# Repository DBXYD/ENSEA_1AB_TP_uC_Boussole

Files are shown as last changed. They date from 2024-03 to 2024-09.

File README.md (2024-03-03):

# ENSEA_1AB_TP_uC_Boussole

## TP

### PCB
Composants : 
* [NUCLEO-L476RG](https://www.st.com/en/evaluation-tools/nucleo-l476rg.html)
* [Magnétomètre 3 axes MMC5603 ADA5579](https://www.gotronic.fr/art-magnetometre-3-axes-mmc5603-ada5579-35829.htm)
* [GPS Tel0094](https://www.gotronic.fr/art-module-gps-tel0094-25732.htm)
* [Microcontroleur pour simulation trame NMEA STM32C011J4M6](https://fr.farnell.com/stmicroelectronics/stm32c011j4m6/mcu-arm-32-bits-48mhz-nsoic-8/dp/4138300)
* [Moteur pas à pas 17hs15-0404s](https://www.gotronic.fr/art-moteur-17hs15-0404s-18354.htm)
* [Driver de moteur pas à pas TMC2225](https://fr.farnell.com/trinamic/tmc2225-sa-t/driver-de-moteur-2a-40-a-125-c/dp/3690353?st=TMC2225-SA-T)
* [Codeur rotatif](https://fr.farnell.com/bourns/pec12r-2220f-s0024/encoder-quadrature-24ppr-15rpm/dp/4014827)
* [Ecran OLED 0.96"](https://www.gotronic.fr/art-afficheur-oled-0-96-i2c-oled01-31506.htm)
* [Mesure de courant NCS199A3RSQT2G](https://fr.farnell.com/on-semiconductor/ncs199a3rsqt2g/ampli-musure-de-cour-40khz-40/dp/2981170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)

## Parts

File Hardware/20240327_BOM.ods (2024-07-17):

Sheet: Farnell
Value | Footprint | MPN | Quantity | Dispo | Farnell | Total
Conn_01x09 | Connector_JST:JST_XH_S9B-XH-A_1x09_P2.50mm_Horizontal | S9B-XH-A (LF)(SN) | 100 | 9249 | 0,21 € | 21,00 €
Conn_01x09 |  | XHP-9 | 100 | 2988 | 0,12 € | 12,00 €
TMC2225-SA-T | Package_SO:HTSSOP-28-1EP_4.4x9.7mm_P0.65mm_EP2.85x5.4mm_ThermalVias | TMC2225-SA-T | 100 | 1035 | 1,58 € | 158,00 €
STM32C011J4Mx | Package_SO:SOIC-8_3.9x4.9mm_P1.27mm | STM32C011J4M6 | 100 | 142 | 0,75 € | 75,00 €
AMS1117-3.3 | Package_TO_SOT_SMD:SOT-223-3_TabPin2 | AZ1117CH2-3.3TRG1 | 100 | 467 | 0,14 € | 14,00 €
 | Connector 2x19 | SSW-119-01-T-D | 250 | 1478 | 3,12 | 780,00 €
NCS199A3RSQT2G | Package_TO_SOT_SMD:SOT-363_SC-70-6 | NCS199A3RSQT2G | 100 | 375 | 0,45 € | 45,00 €
SW_Push_DPDT | Button_Switch_SMD:SW_DPDT_CK_JS202011JCQN | JS202011JCQN | 100 | 3904 | 0,51 € | 51,00 €
Conn_03x06 |  | SAMTEC TSW-106-05-F-T | 100 | 0 |  | 0,00 €
110m | Resistor_SMD:R_0603_1608Metric_Pad0.98x0.95mm_HandSolder | MFL0603R1100FB | 100 | 4970 | 0,08 € | 8,00 €
680m | Resistor_SMD:R_1206_3216Metric_Pad1.30x1.75mm_HandSolder | WW12PR680FTL | 200 | 2340 | 0,13 € | 26,00 €
400m | Resistor_SMD:R_0402_1005Metric | WW04PR400FTL | 200 | 5660 | 0,104 | 20,80 €
 | Alimentation 230VAC/12VDC | PELL0219 | 100 | 177 | 4,80 € | 480,00 €
 |  |  |  |  |  | 1 690,80 €

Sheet: WE
Value | Footprint | MPN | Quantity | Dispo | WE | Total | MPN | Quantity
10n | Capacitor_SMD:C_0402_1005Metric | WE 885012205050 | 900 |  | 0,01 € | 6,30 € | WE 885012205050 | 1000
22n | Capacitor_SMD:C_0402_1005Metric | WE 885012205052 | 100 |  | 0,01 € | 1,20 € | WE 885012205052 | 500
100n | Capacitor_SMD:C_0402_1005Metric | WE 885012105018 | 700 |  | 0,02 € | 14,70 € | WE 885012105018 | 1000
1u | Capacitor_SMD:C_0402_1005Metric | WE 885012105012 | 300 |  | 0,20 € | 60,90 € | WE 885012105012 | 500
10u | Capacitor_SMD:C_0402_1005Metric | WE 885012105020 | 200 |  | 0,28 € | 55,00 € | WE 885012105020 | 500
10u | Capacitor_SMD:CP_Elec_4x5.7 | WE 865060440001 | 200 |  | 0,16 € | 31,80 € | WE 865060440001 | 200
4u7 | Capacitor_SMD:C_0402_1005Metric | WE 885012105008 | 200 |  | 0,22 € | 44,80 € | WE 885012105008 | 200
 | Step-down 5V | WE 173010542 | 100 |  | 8,94 € | 894,00 € | WE 173010542 | 100
AMBER_LED | LED_SMD:LED_0603_1608Metric | WE 150060AS55040 | 100 |  | 0,12 € | 11,60 € | WE 150060AS55040 | 500
GREEN_LED | LED_SMD:LED_0603_1608Metric | WE 150060GS55040 | 500 |  | 0,18 € | 91,00 € | WE 150060GS55040 | 500
RED_LED | LED_SMD:LED_0603_1608Metric | WE 150060RS55040 | 600 |  | 0,15 € | 87,60 € | WE 150060RS55040 | 1000
YELLOW_LED | LED_SMD:LED_0603_1608Metric | WE 150060YS55040 | 100 |  | 0,15 € | 14,60 € | WE 150060YS55040 | 500
Conn_02x02_Counter_Clockwise | Connector_PinHeader_2.54mm:PinHeader_2x02_P2.54mm_Vertical_SMD | WE 61000421121 | 100 |  | 0,49 € | 49,00 € | WE 61000421121 | 200
Conn_02x10_Odd_Even | Connector_PinHeader_2.54mm:PinHeader_2x10_P2.54mm_Vertical_SMD | WE 61002021121 | 100 |  | 1,85 € | 185,00 € | WE 61000621121 | 100
RotaryEncoder_Switch | libs:482016514001_Mechanical_Incremental_Encoder_Switch | WE 482016514001 | 100 |  | 2,96 € | 296,00 € | WE 61000821121 | 100
SW_Push | Button_Switch_SMD:SW_Push_1P1T_NO_6x6mm_H9.5mm | WE 430182070816 | 700 |  | 0,41 € | 289,10 € | WE 61001021121 | 100
SW_SPDT | libs:472121020311 | WE 472121020311 | 100 |  | 5,32 € | 532,00 € | WE 61001221121 | 100
 | libs:SC70-5L | WE 82402374 | 600 |  | 0,58 € | 346,80 € | WE 61001421121 | 100
 | libs:SC70-6L | WE 82402375 | 200 |  | 0,59 € | 117,40 € | WE 61001621121 | 100
 |  |  |  |  |  | 3 128,80 € | WE 61002021121 | 200
 |  |  |  |  |  |  | WE 482016514001 | 150
 |  |  |  |  |  |  | WE 430182070816 | 1000
 |  |  |  |  |  |  | WE 472121020311 | 200
 |  |  |  |  |  |  | WE 82402374 | 1000
 |  |  |  |  |  |  | WE 82402375 | 500

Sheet: Gotronic
Value | Code Gotronic | MPN | Quantity | Dispo | Tarif | Total
Stepper | 31115 | 14HM11-0404S | 100 | 24 | 18,58 | 1 858,00 €
Magnétomètre | 37683 | BMM150 SEN0419 | 100 | 22 | 6,92 | 692,00 €
GPS | 35014 | TEL0094 | 100 | 15 | 15,5 | 1 550,00 €
OLED | 36688 | SBC-01 | 100 | 168 | 6,25 | 625,00 €
 |  |  |  |  |  | 4 725,00 €

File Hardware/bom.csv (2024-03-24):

Value | Footprint | MPN | Quantity | Dispo | Farnell | Total
Conn_01x09 | Connector_JST:JST_XH_S9B-XH-A_1x09_P2.50mm_Horizontal | S9B-XH-A (LF)(SN) | 100 | 9249 | 0,21 € | 20,90 €
Conn_01x09 |  | XHP-9 | 100 | 2988 | 0,12 € | 12,10 €
TMC2225-SA-T | Package_SO:HTSSOP-28-1EP_4.4x9.7mm_P0.65mm_EP2.85x5.4mm_ThermalVias | TMC2225-SA-T | 100 | 1035 | 1,58 € | 158,00 €
STM32C011J4Mx | Package_SO:SOIC-8_3.9x4.9mm_P1.27mm | STM32C011J4M6 | 100 | 142 | 0,75 € | 75,40 €
AMS1117-3.3 | Package_TO_SOT_SMD:SOT-223-3_TabPin2 | AZ1117CH2-3.3TRG1 | 100 | 467 | 0,14 € | 13,70 €
 | Connector 2x19 | TSW-119-19-T-D | 250 | 1478 | 1,51 € | 377,50 €
NCS199A3RSQT2G | Package_TO_SOT_SMD:SOT-363_SC-70-6 | NCS199A3RSQT2G | 100 | 375 | 0,45 € | 44,70 €
SW_Push_DPDT | Button_Switch_SMD:SW_DPDT_CK_JS202011JCQN | JS202011JCQN | 100 | 3904 | 0,51 € | 51,30 €
Conn_03x06 |  | SAMTEC TSW-106-05-F-T | 100 | 0 |  | 0,00 €
110m | Resistor_SMD:R_0603_1608Metric_Pad0.98x0.95mm_HandSolder | MFL0603R1100FB | 100 | 4970 | 0,08 € | 8,20 €
680m | Resistor_SMD:R_1206_3216Metric_Pad1.30x1.75mm_HandSolder | WW12PR680FTL | 200 | 2340 | 0,13 € | 25,20 €
30m | Resistor_SMD:R_0402_1005Metric | ERJ2RKF30R1X | 100 | 31860 | 0,01 € | 0,50 €
 | Alimentation 230VAC/12VDC | PELL0219 | 100 | 177 | 4,80 € | 480,00 €
 |  |  |  |  |  | 1 267,50 €

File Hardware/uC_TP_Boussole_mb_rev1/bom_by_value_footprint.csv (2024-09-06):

Reference | Value | Datasheet | Footprint | Qty | DNP
C201,C203 | 10u | ~ | Capacitor_SMD:CP_Elec_4x5.7 | 2
C202,C205,C302,C304,C404,C601,C904 | 100n | ~ | Capacitor_SMD:C_0402_1005Metric | 7
C204 | 22n | ~ | Capacitor_SMD:C_0402_1005Metric | 1
C206,C301 | 4u7 | ~ | Capacitor_SMD:C_0402_1005Metric | 2
C303,C501,C502,C503,C504,C505,C901,C902,C903 | 10n | ~ | Capacitor_SMD:C_0402_1005Metric | 9
C305,C701,C801 | 1u | ~ | Capacitor_SMD:C_0402_1005Metric | 3
C401,C403 | 10u | ~ | Capacitor_SMD:C_0402_1005Metric | 2
C402 | 22u | ~ | Capacitor_SMD:CP_Elec_5x5.4 | 1
D201,D301,D401,D402,D403,D502 | RED_LED | https://www.we-online.com/components/products/datasheet/150060RS55040.pdf | LED_SMD:LED_0603_1608Metric | 6
D302,D511 | WE 82402375 | https://www.we-online.com/components/products/datasheet/82402375.pdf | libs:SC70-6L | 2
D501,D510,D701,D702,D801,D901 | WE 82402374 | https://www.we-online.com/components/products/datasheet/82402374.pdf | libs:SC70-5L | 6
D503 | AMBER_LED | https://www.we-online.com/components/products/datasheet/150060AS55040.pdf | LED_SMD:LED_0603_1608Metric | 1
D504 | YELLOW_LED | https://www.we-online.com/components/products/datasheet/150060YS55040.pdf | LED_SMD:LED_0603_1608Metric | 1
D505,D506,D507,D508,D509 | GREEN_LED | https://www.we-online.com/components/products/datasheet/150060GS55040.pdf | LED_SMD:LED_0603_1608Metric | 5
H101,H102,H103,H104,H105,H106,H107,H108 | MountingHole_Pad | ~ | MountingHole:MountingHole_3.2mm_M3_Pad | 8
J201 | Conn_01x04 | ~ | Connector_JST:JST_XH_B4B-XH-A_1x04_P2.50mm_Vertical | 1
J302 | Conn_01x04 | ~ | libs:Grove_PHS-4AW | 1
J303 | Conn_01x06 | ~ | Connector_PinHeader_2.54mm:PinHeader_1x06_P2.54mm_Vertical_SMD_Pin1Left | 1
J402 | Conn_02x02_Counter_Clockwise | https://www.we-online.com/components/products/datasheet/61000421121.pdf | Connector_PinHeader_2.54mm:PinHeader_2x02_P2.54mm_Vertical_SMD | 1
J403 | Barrel_Jack_Switch | ~ | libs:694106105102 | 1
J501,J502,J503 | Conn_01x06 | ~ | Connector_PinHeader_2.54mm:PinHeader_1x06_P2.54mm_Vertical | 3
J504 | Conn_02x10_Odd_Even | https://www.we-online.com/components/products/datasheet/61002021121.pdf | Connector_PinHeader_2.54mm:PinHeader_2x10_P2.54mm_Vertical_SMD | 1
J701 | Conn_01x09 | ~ | Connector_JST:JST_XH_S9B-XH-A_1x09_P2.50mm_Horizontal | 1
J801 | Conn_01x04 | ~ | libs:SBC-OLED01 | 1
R201 | 110m | ~ | Resistor_SMD:R_0603_1608Metric_Pad0.98x0.95mm_HandSolder | 1
R202,R203 | 680m | ~ | Resistor_SMD:R_1206_3216Metric_Pad1.30x1.75mm_HandSolder | 2
R204,R404 | 820 | ~ | Resistor_SMD:R_0402_1005Metric | 2
R301,R302,R509,R510,R511,R512,R513,R514,R515,R516,R517,R518,R901,R902,R903,R904,R905,R906 | 10k | ~ | Resistor_SMD:R_0402_1005Metric | 18
R303,R501,R503 | 800 | ~ | Resistor_SMD:R_0402_1005Metric | 3
R401 | 1k | ~ | Resistor_SMD:R_0805_2012Metric | 1
R402 | 5k1 | ~ | Resistor_SMD:R_0402_1005Metric | 1
R403 | 1k6 | ~ | Resistor_SMD:R_0402_1005Metric | 1
R502 | 850 | ~ | Resistor_SMD:R_0402_1005Metric | 1
R504,R505,R506,R507,R508 | 400 | ~ | Resistor_SMD:R_0402_1005Metric | 5
R601 | 400m | ~ | Resistor_SMD:R_0402_1005Metric | 1
R801,R802 | 1k | ~ | Resistor_SMD:R_0402_1005Metric | 2
SW301,SW302,SW501,SW502,SW503,SW504,SW505 | SW_Push | ~ | Button_Switch_SMD:SW_Push_1P1T_NO_6x6mm_H9.5mm | 7
SW303 | SW_Push_DPDT | ~ | Button_Switch_SMD:SW_DPDT_CK_JS202011JCQN | 1
SW401 | SW_SPDT | https://www.we-online.com/components/products/datasheet/472121020311.pdf | libs:472121020311 | 1
SW901 | RotaryEncoder_Switch | https://www.we-online.com/components/products/datasheet/482016514001.pdf | libs:482016514001_Mechanical_Incremental_Encoder_Switch | 1
U201 | TMC2225-SA-T | https://www.analog.com/media/en/technical-documentation/data-sheets/TMC2225_datasheet_rev1.15.pdf | Package_SO:HTSSOP-28-1EP_4.4x9.7mm_P0.65mm_EP2.85x5.4mm_ThermalVias | 1
U301 | STM32C011J4Mx | https://www.st.com/resource/en/datasheet/stm32c011j4.pdf | Package_SO:SOIC-8_3.9x4.9mm_P1.27mm | 1
U401 | 173010542 | https://www.we-online.com/components/products/datasheet/173010542.pdf | libs:173010xxx | 1
U402 | AZ1117CH2-3.3TRG1 | https://4donline.ihs.com/images/VipMasterIC/IC/DIOD/DIOD-S-A0007713706/DIOD-S-A0007713706-1.pdf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 | Package_TO_SOT_SMD:SOT-223-3_TabPin2 | 1
U501 | NUCLEO_L476RG |  | libs:ST_NUCLEO_64 | 1
U601 | NCS199A3RSQT2G | https://www.mouser.fr/datasheet/2/308/1/NCS199A1R_D-2317315.pdf | Package_TO_SOT_SMD:SOT-363_SC-70-6 | 1

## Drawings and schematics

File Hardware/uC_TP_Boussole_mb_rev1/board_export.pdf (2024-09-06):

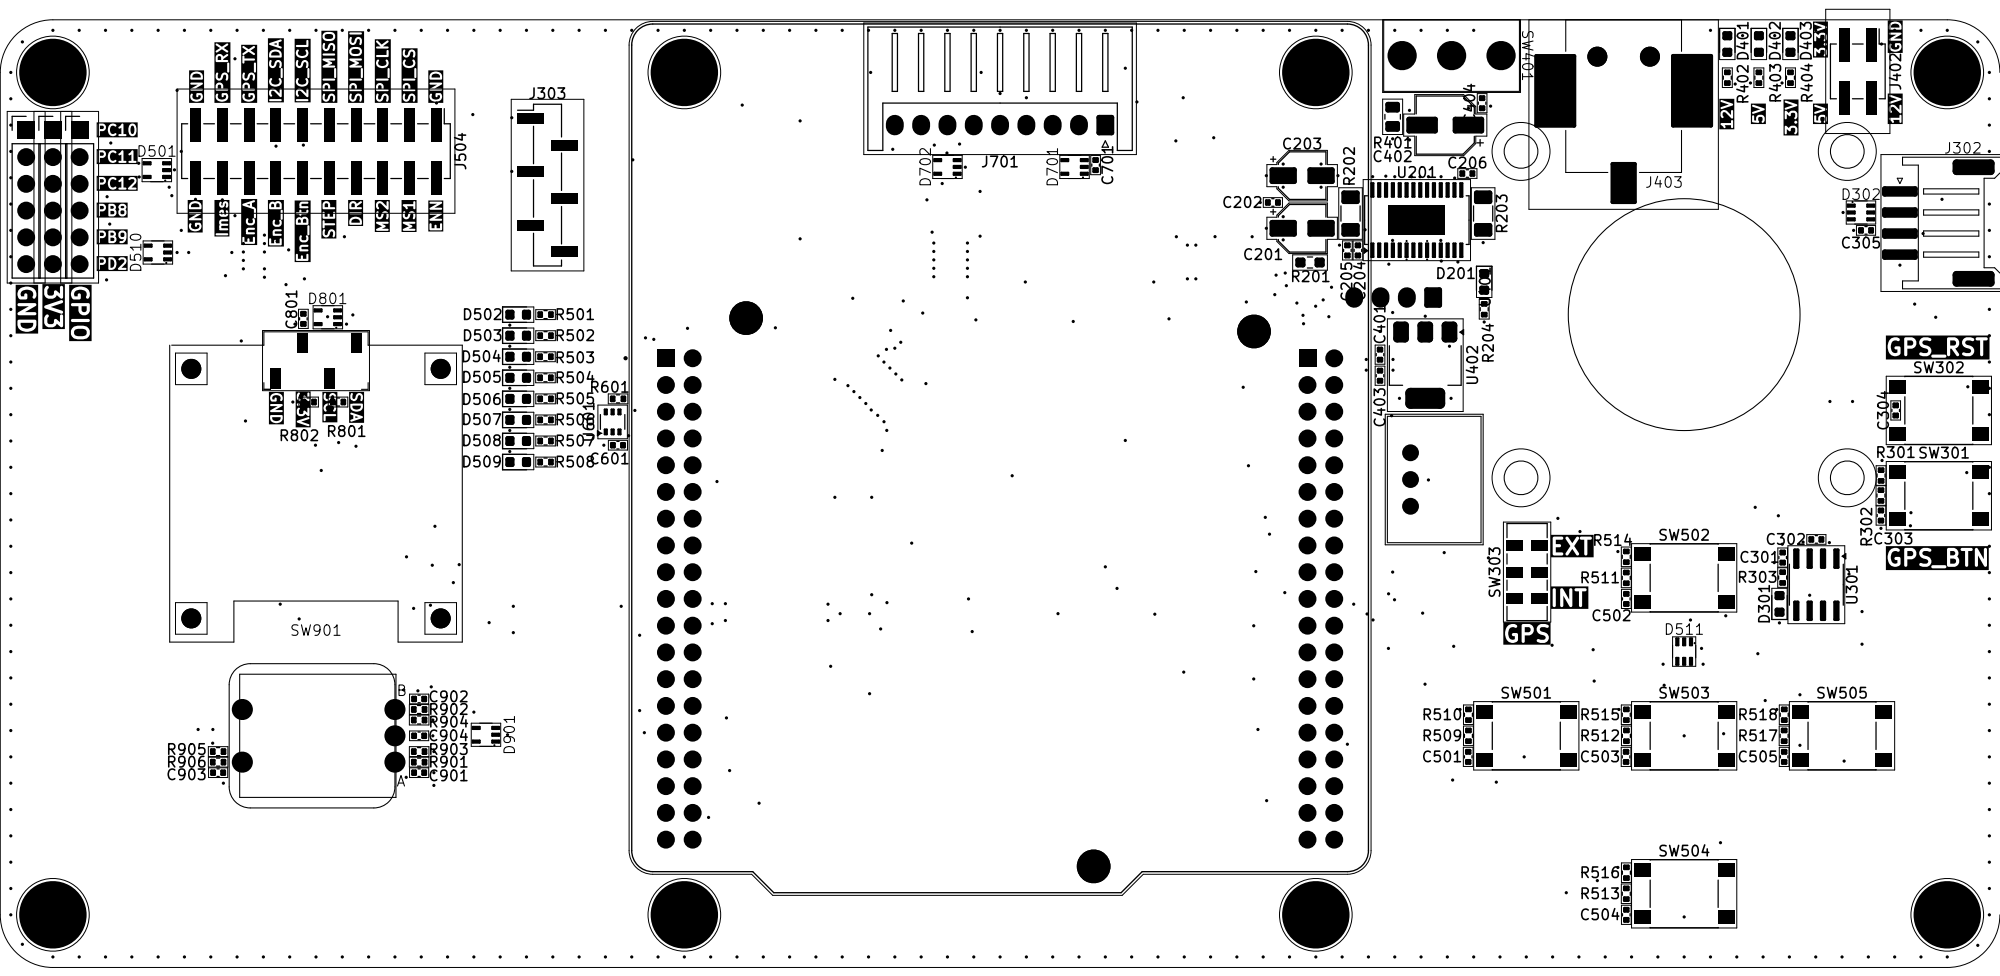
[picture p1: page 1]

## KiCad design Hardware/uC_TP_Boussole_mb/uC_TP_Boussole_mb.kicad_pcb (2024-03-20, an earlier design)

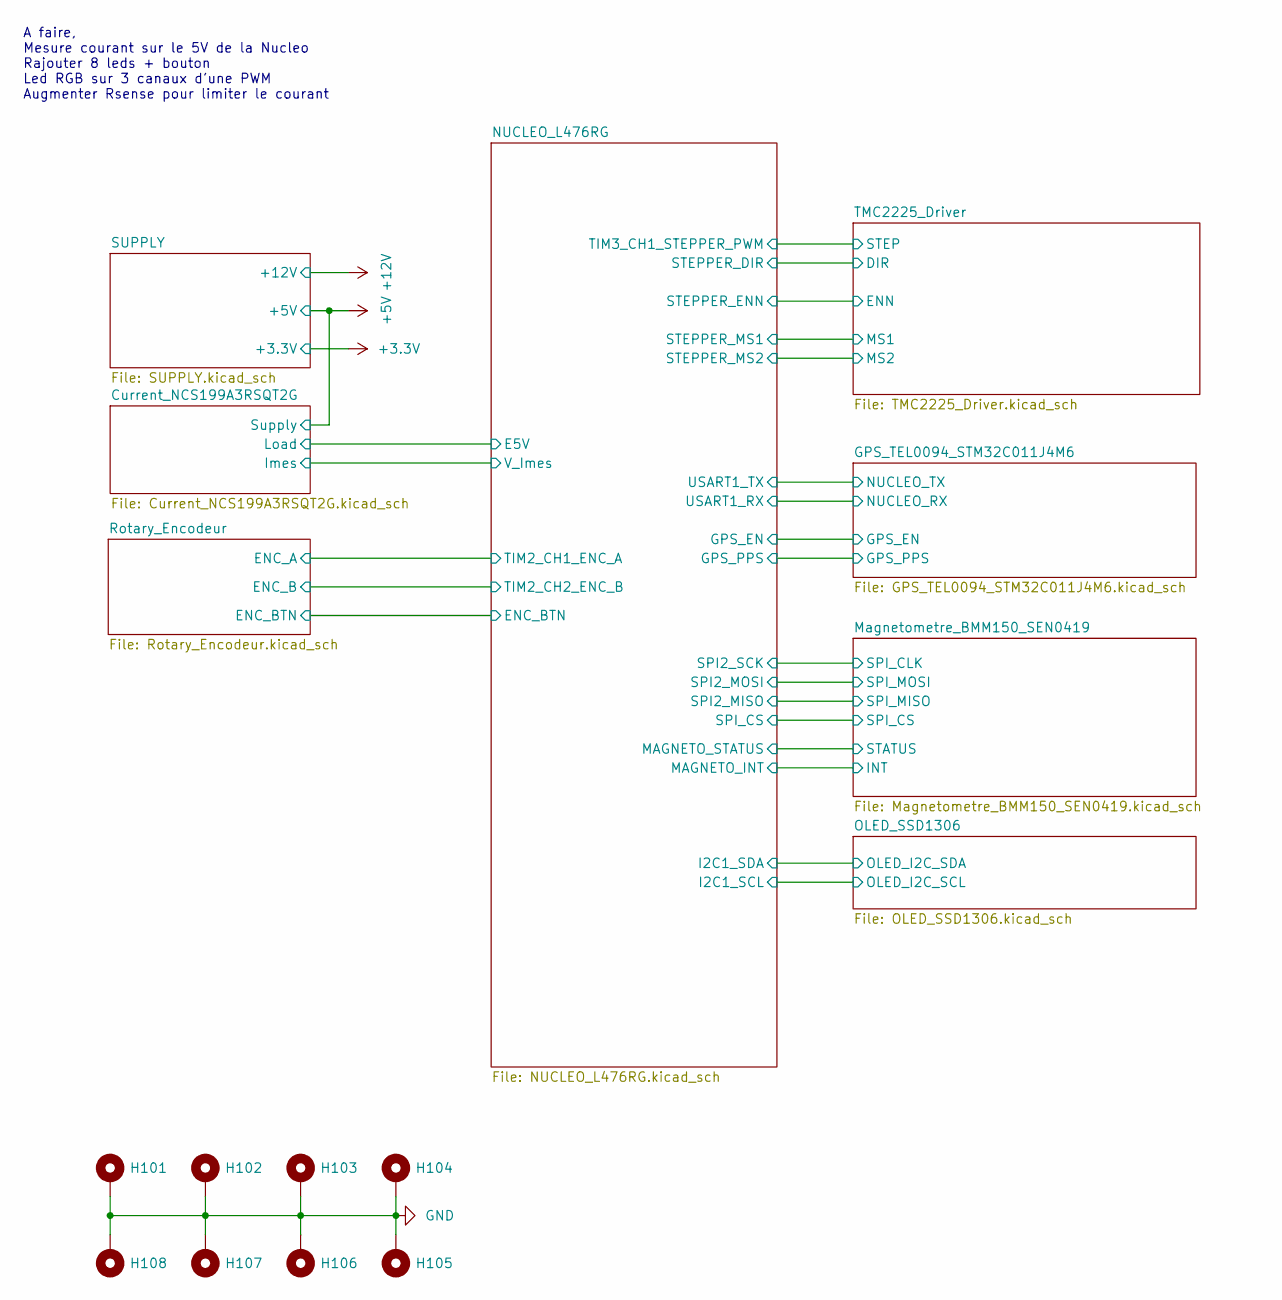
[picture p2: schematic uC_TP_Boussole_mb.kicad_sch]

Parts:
H101, H102, H103, H104, H105, H106, H107, H108: MountingHole_Pad; MountingHole_3.2mm_M3_Pad

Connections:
GND: H101.1, H102.1, H103.1, H104.1, H105.1, H106.1, H107.1, H108.1; also elsewhere on the board

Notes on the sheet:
A faire, Mesure courant sur le 5V de la Nucleo Rajouter 8 leds + bouton Led RGB sur 3 canaux d'une PWM Augmenter Rsense pour limiter le courant

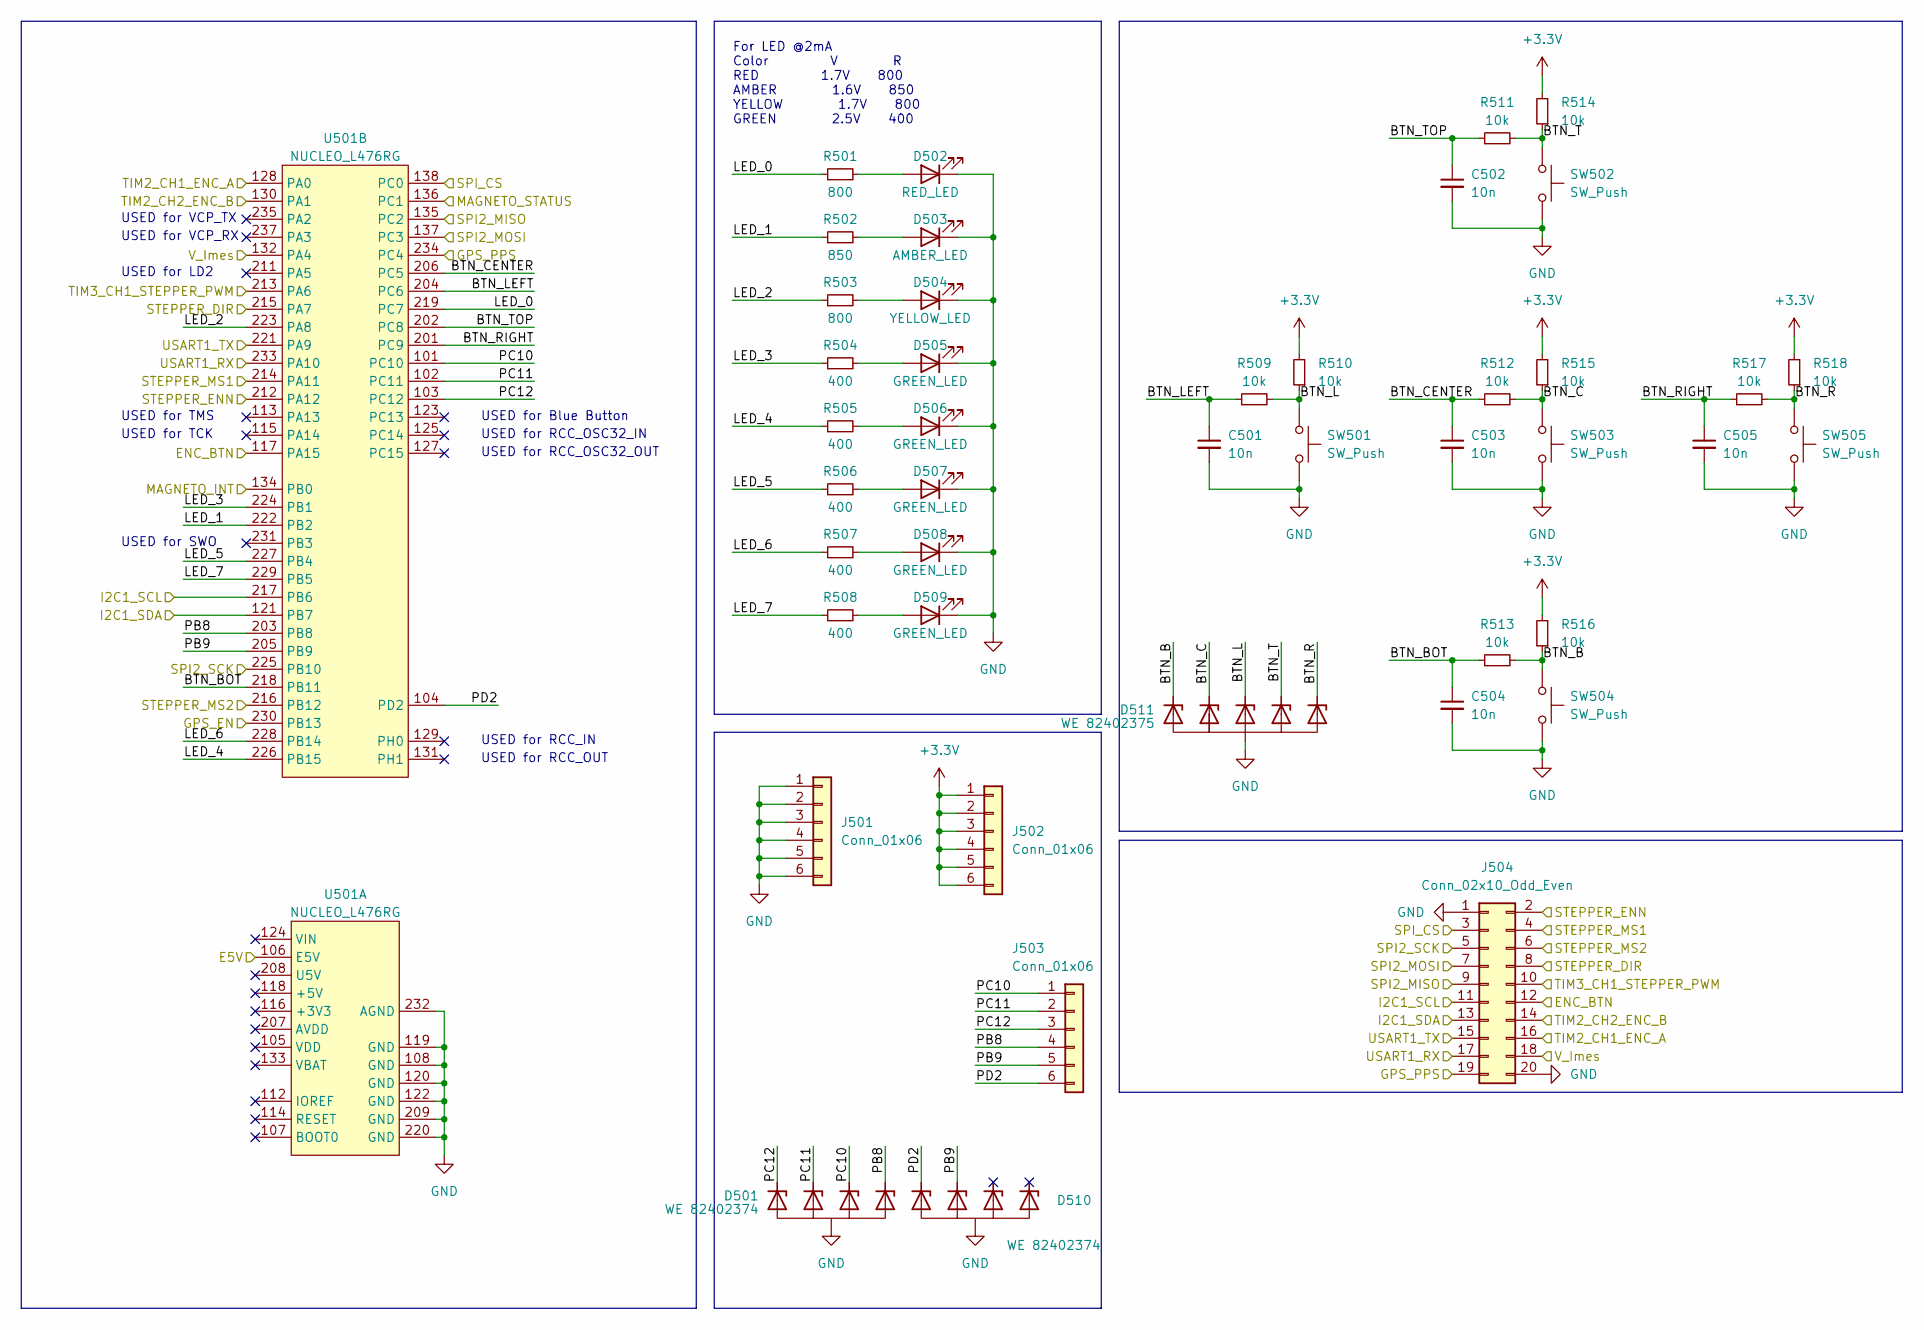
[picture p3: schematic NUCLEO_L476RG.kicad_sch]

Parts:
C501, C502, C503, C504, C505: 10n; C_0402_1005Metric; MPN WE 885012205050
D501, D510: WE 82402374; SC70-5L; MPN WE 82402374
D502: RED_LED; LED_0603_1608Metric; MPN WE 150060RS55040
D503: AMBER_LED; LED_0603_1608Metric; MPN WE 150060AS55040
D504: YELLOW_LED; LED_0603_1608Metric; MPN WE 150060YS55040
D505, D506, D507, D508, D509: GREEN_LED; LED_0603_1608Metric; MPN WE 150060GS55040
D511: WE 82402375; SC70-6L; MPN WE 82402375
J501, J502, J503: Conn_01x06; PinHeader_1x06_P2.54mm_Vertical; MPN SAMTEC TSW-106-05-F-T
J504: Conn_02x10_Odd_Even; PinHeader_2x10_P2.54mm_Vertical_SMD; MPN WE 61002021121
R501, R503: 800; R_0402_1005Metric
R502: 850; R_0402_1005Metric
R504, R505, R506, R507, R508: 400; R_0402_1005Metric
R509, R510, R511, R512, R513, R514, R515, R516, R517, R518: 10k; R_0402_1005Metric
SW501, SW502, SW503, SW504, SW505: SW_Push; SW_Push_1P1T_NO_6x6mm_H9.5mm; MPN WE 430182070816
U501: NUCLEO_L476RG; ST_NUCLEO_64; MPN TSW-119-19-T-D

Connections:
+3.3V: J502.1, J502.2, J502.3, J502.4, J502.5, J502.6, R510.2, R514.2, R515.2, R516.2, R518.2; also elsewhere on the board
/Current_NCS199A3RSQT2G/Imes: J504.18, U501.132 (PA4); also elsewhere on the board
/Current_NCS199A3RSQT2G/Load: U501.106 (E5V); also elsewhere on the board
/GPS_TEL0094_STM32C011J4M6/GPS_EN: U501.230 (PB13); also elsewhere on the board
/GPS_TEL0094_STM32C011J4M6/GPS_PPS: J504.19, U501.234 (PC4); also elsewhere on the board
/GPS_TEL0094_STM32C011J4M6/NUCLEO_RX: J504.17, U501.233 (PA10); also elsewhere on the board
/GPS_TEL0094_STM32C011J4M6/NUCLEO_TX: J504.15, U501.221 (PA9); also elsewhere on the board
/Magnetometre_BMM150_SEN0419/INT: U501.134 (PB0); also elsewhere on the board
/Magnetometre_BMM150_SEN0419/SPI_CLK: J504.5, U501.225 (PB10); also elsewhere on the board
/Magnetometre_BMM150_SEN0419/SPI_CS: J504.3, U501.138 (PC0); also elsewhere on the board
/Magnetometre_BMM150_SEN0419/SPI_MISO: J504.9, U501.135 (PC2); also elsewhere on the board
/Magnetometre_BMM150_SEN0419/SPI_MOSI: J504.7, U501.137 (PC3); also elsewhere on the board
/Magnetometre_BMM150_SEN0419/STATUS: U501.136 (PC1); also elsewhere on the board
/NUCLEO_L476RG/BTN_B: D511.6 (I/O), R513.2, R516.1, SW504.1
/NUCLEO_L476RG/BTN_BOT: C504.1, R513.1, U501.218 (PB11)
/NUCLEO_L476RG/BTN_C: D511.5 (I/O), R512.2, R515.1, SW503.1
/NUCLEO_L476RG/BTN_CENTER: C503.1, R512.1, U501.206 (PC5)
/NUCLEO_L476RG/BTN_L: D511.4 (I/O), R509.2, R510.1, SW501.1
/NUCLEO_L476RG/BTN_LEFT: C501.1, R509.1, U501.204 (PC6)
/NUCLEO_L476RG/BTN_R: D511.1 (I/O), R517.2, R518.1, SW505.1
/NUCLEO_L476RG/BTN_RIGHT: C505.1, R517.1, U501.201 (PC9)
/NUCLEO_L476RG/BTN_T: D511.3 (I/O), R511.2, R514.1, SW502.1
/NUCLEO_L476RG/BTN_TOP: C502.1, R511.1, U501.202 (PC8)
/NUCLEO_L476RG/ENC_BTN: J504.12, U501.117 (PA15); also elsewhere on the board
/NUCLEO_L476RG/I2C1_SCL: J504.11, U501.217 (PB6); also elsewhere on the board
/NUCLEO_L476RG/I2C1_SDA: J504.13, U501.121 (PB7); also elsewhere on the board
/NUCLEO_L476RG/LED_0: R501.1, U501.219 (PC7)
/NUCLEO_L476RG/LED_1: R502.1, U501.222 (PB2)
/NUCLEO_L476RG/LED_2: R503.1, U501.223 (PA8)
/NUCLEO_L476RG/LED_3: R504.1, U501.224 (PB1)
/NUCLEO_L476RG/LED_4: R505.1, U501.226 (PB15)
/NUCLEO_L476RG/LED_5: R506.1, U501.227 (PB4)
/NUCLEO_L476RG/LED_6: R507.1, U501.228 (PB14)
/NUCLEO_L476RG/LED_7: R508.1, U501.229 (PB5)
/NUCLEO_L476RG/PB8: D501.1 (I/O), J503.4, U501.203 (PB8)
/NUCLEO_L476RG/PB9: D510.4 (I/O), J503.5, U501.205 (PB9)
/NUCLEO_L476RG/PC10: D501.3 (I/O), J503.1, U501.101 (PC10)
/NUCLEO_L476RG/PC11: D501.4 (I/O), J503.2, U501.102 (PC11)
/NUCLEO_L476RG/PC12: D501.5 (I/O), J503.3, U501.103 (PC12)
/NUCLEO_L476RG/PD2: D510.5 (I/O), J503.6, U501.104 (PD2)
/NUCLEO_L476RG/STEPPER_DIR: J504.8, U501.215 (PA7); also elsewhere on the board
/NUCLEO_L476RG/STEPPER_ENN: J504.2, U501.212 (PA12); also elsewhere on the board
/NUCLEO_L476RG/STEPPER_MS1: J504.4, U501.214 (PA11); also elsewhere on the board
/NUCLEO_L476RG/STEPPER_MS2: J504.6, U501.216 (PB12); also elsewhere on the board
/NUCLEO_L476RG/TIM2_CH1_ENC_A: J504.16, U501.128 (PA0); also elsewhere on the board
/NUCLEO_L476RG/TIM2_CH2_ENC_B: J504.14, U501.130 (PA1); also elsewhere on the board
/NUCLEO_L476RG/TIM3_CH1_STEPPER_PWM: J504.10, U501.213 (PA6); also elsewhere on the board
GND: C501.2, C502.2, C503.2, C504.2, C505.2, D501.2 (GND), D502.1 (K), D503.1 (K), D504.1 (K), D505.1 (K), D506.1 (K), D507.1 (K), D508.1 (K), D509.1 (K), D510.2 (GND), D511.2 (GND), J501.1, J501.2, J501.3, J501.4, J501.5, J501.6, J504.1, J504.20, SW501.2, SW502.2, SW503.2, SW504.2, SW505.2, U501.108 (GND), U501.119 (GND), U501.120 (GND), U501.122 (GND), U501.209 (GND), U501.220 (GND), U501.232 (AGND); also elsewhere on the board
unnamed: D502.2 (A), R501.2
unnamed: D503.2 (A), R502.2
unnamed: D504.2 (A), R503.2
unnamed: D505.2 (A), R504.2
unnamed: D506.2 (A), R505.2
unnamed: D507.2 (A), R506.2
unnamed: D508.2 (A), R507.2
unnamed: D509.2 (A), R508.2

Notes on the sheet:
USED for SWO
USED for RCC_OUT
USED for VCP_RX
USED for RCC_OSC32_IN
USED for Blue Button
USED for RCC_IN
USED for RCC_OSC32_OUT
For LED @2mA Color V R RED 1.7V 800 AMBER 1.6V 850 YELLOW 1.7V 800 GREEN 2.5V 400
USED for TMS
USED for TCK
USED for VCP_TX
USED for LD2

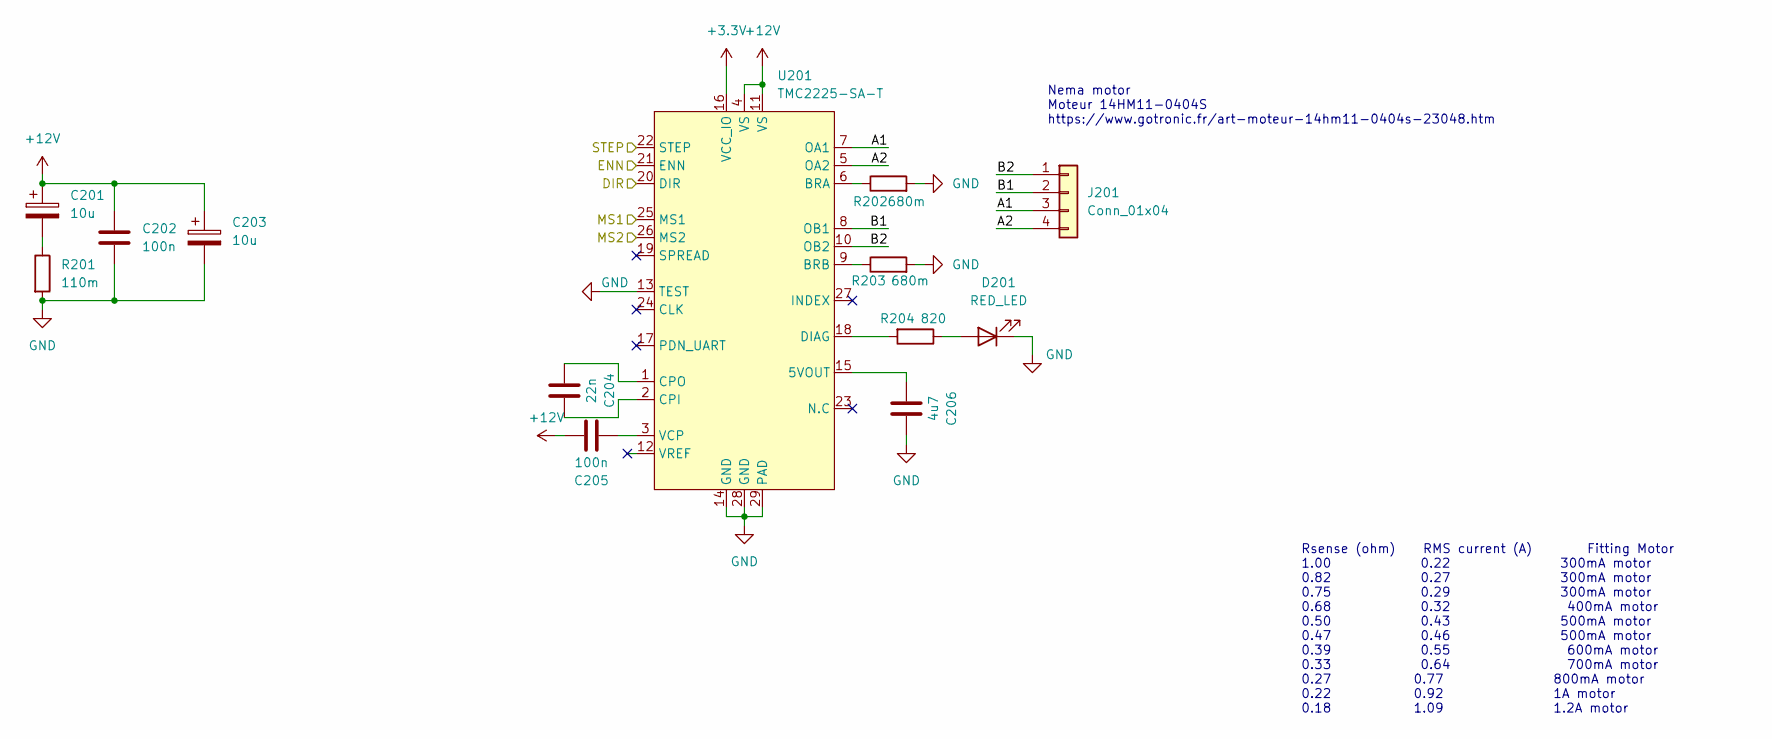
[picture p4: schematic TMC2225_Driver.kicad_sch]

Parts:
C201, C203: 10u; CP_Elec_4x5.7; MPN WE 865060440001
C202, C205: 100n; C_0402_1005Metric; MPN WE 885012105018
C204: 22n; C_0402_1005Metric; MPN WE 885012205052
C206: 4u7; C_0402_1005Metric; MPN WE 885012105008
D201: RED_LED; LED_0603_1608Metric; MPN WE 150060RS55040
J201: Conn_01x04; JST_XH_S4B-XH-A_1x04_P2.50mm_Horizontal; MPN S4B-XH-A(lf)(sn)
R201: 110m; R_0603_1608Metric_Pad0.98x0.95mm_HandSolder; MPN MFL0603R1100FB
R202, R203: 680m; R_1206_3216Metric_Pad1.30x1.75mm_HandSolder; MPN WW12PR680FTL
R204: 820; R_0402_1005Metric
U201: TMC2225-SA-T; HTSSOP-28-1EP_4.4x9.7mm_P0.65mm_EP2.85x5.4mm_ThermalVias; MPN TMC2225-SA-T

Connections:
+3.3V: U201.16 (VCC_IO); also elsewhere on the board
+12V: C201.1, C202.1, C203.1, C205.1, U201.4 (VS), U201.11 (VS); also elsewhere on the board
/NUCLEO_L476RG/STEPPER_DIR: U201.20 (DIR); also elsewhere on the board
/NUCLEO_L476RG/STEPPER_ENN: U201.21 (ENN); also elsewhere on the board
/NUCLEO_L476RG/STEPPER_MS1: U201.25 (MS1); also elsewhere on the board
/NUCLEO_L476RG/STEPPER_MS2: U201.26 (MS2); also elsewhere on the board
/NUCLEO_L476RG/TIM3_CH1_STEPPER_PWM: U201.22 (STEP); also elsewhere on the board
/TMC2225_Driver/A1: J201.3, U201.7 (OA1)
/TMC2225_Driver/A2: J201.4, U201.5 (OA2)
/TMC2225_Driver/B1: J201.2, U201.8 (OB1)
/TMC2225_Driver/B2: J201.1, U201.10 (OB2)
GND: C202.2, C203.2, C206.1, D201.1 (K), R201.2, R202.2, R203.2, U201.13 (TEST), U201.14 (GND), U201.28 (GND), U201.29 (PAD); also elsewhere on the board
unnamed: C201.2, R201.1
unnamed: D201.2 (A), R204.1
unnamed: C206.2, U201.15 (5VOUT)
unnamed: R202.1, U201.6 (BRA)
unnamed: R203.1, U201.9 (BRB)
unnamed: C204.1, U201.2 (CPI)
unnamed: C204.2, U201.1 (CPO)
unnamed: R204.2, U201.18 (DIAG)
unnamed: C205.2, U201.3 (VCP)

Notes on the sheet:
Rsense (ohm) RMS current (A) Fitting Motor 1.00 0.22 300mA motor 0.82 0.27 300mA motor 0.75 0.29 300mA motor 0.68 0.32 400mA motor 0.50 0.43 500mA motor 0.47 0.46 500mA motor 0.39 0.55 600mA motor 0.33 0.64 700mA motor 0.27 0.77 800mA motor 0.22 0.92 1A motor 0.18 1.09 1.2A motor
Nema motor Moteur 14HM11-0404S https://www.gotronic.fr/art-moteur-14hm11-0404s-23048.htm

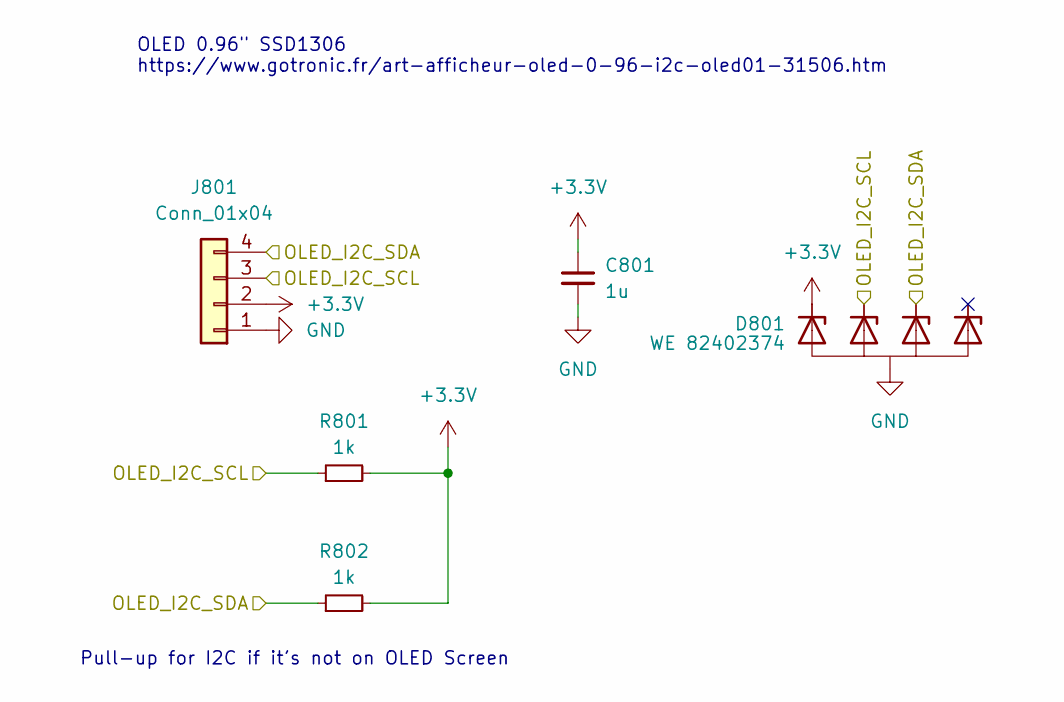
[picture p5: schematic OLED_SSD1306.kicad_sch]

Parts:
C801: 1u; C_0402_1005Metric; MPN WE 885012105012
D801: WE 82402374; SC70-5L; MPN WE 82402374
J801: Conn_01x04; SBC-OLED01; MPN Joy-it SBC-OLED01
R801, R802: 1k; R_0402_1005Metric

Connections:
+3.3V: C801.1, D801.5 (I/O), J801.2, R801.2, R802.2; also elsewhere on the board
/NUCLEO_L476RG/I2C1_SCL: D801.4 (I/O), J801.3, R801.1; also elsewhere on the board
/NUCLEO_L476RG/I2C1_SDA: D801.3 (I/O), J801.4, R802.1; also elsewhere on the board
GND: C801.2, D801.2 (GND), J801.1; also elsewhere on the board

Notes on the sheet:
OLED 0.96" SSD1306 https://www.gotronic.fr/art-afficheur-oled-0-96-i2c-oled01-31506.htm
Pull-up for I2C if it's not on OLED Screen

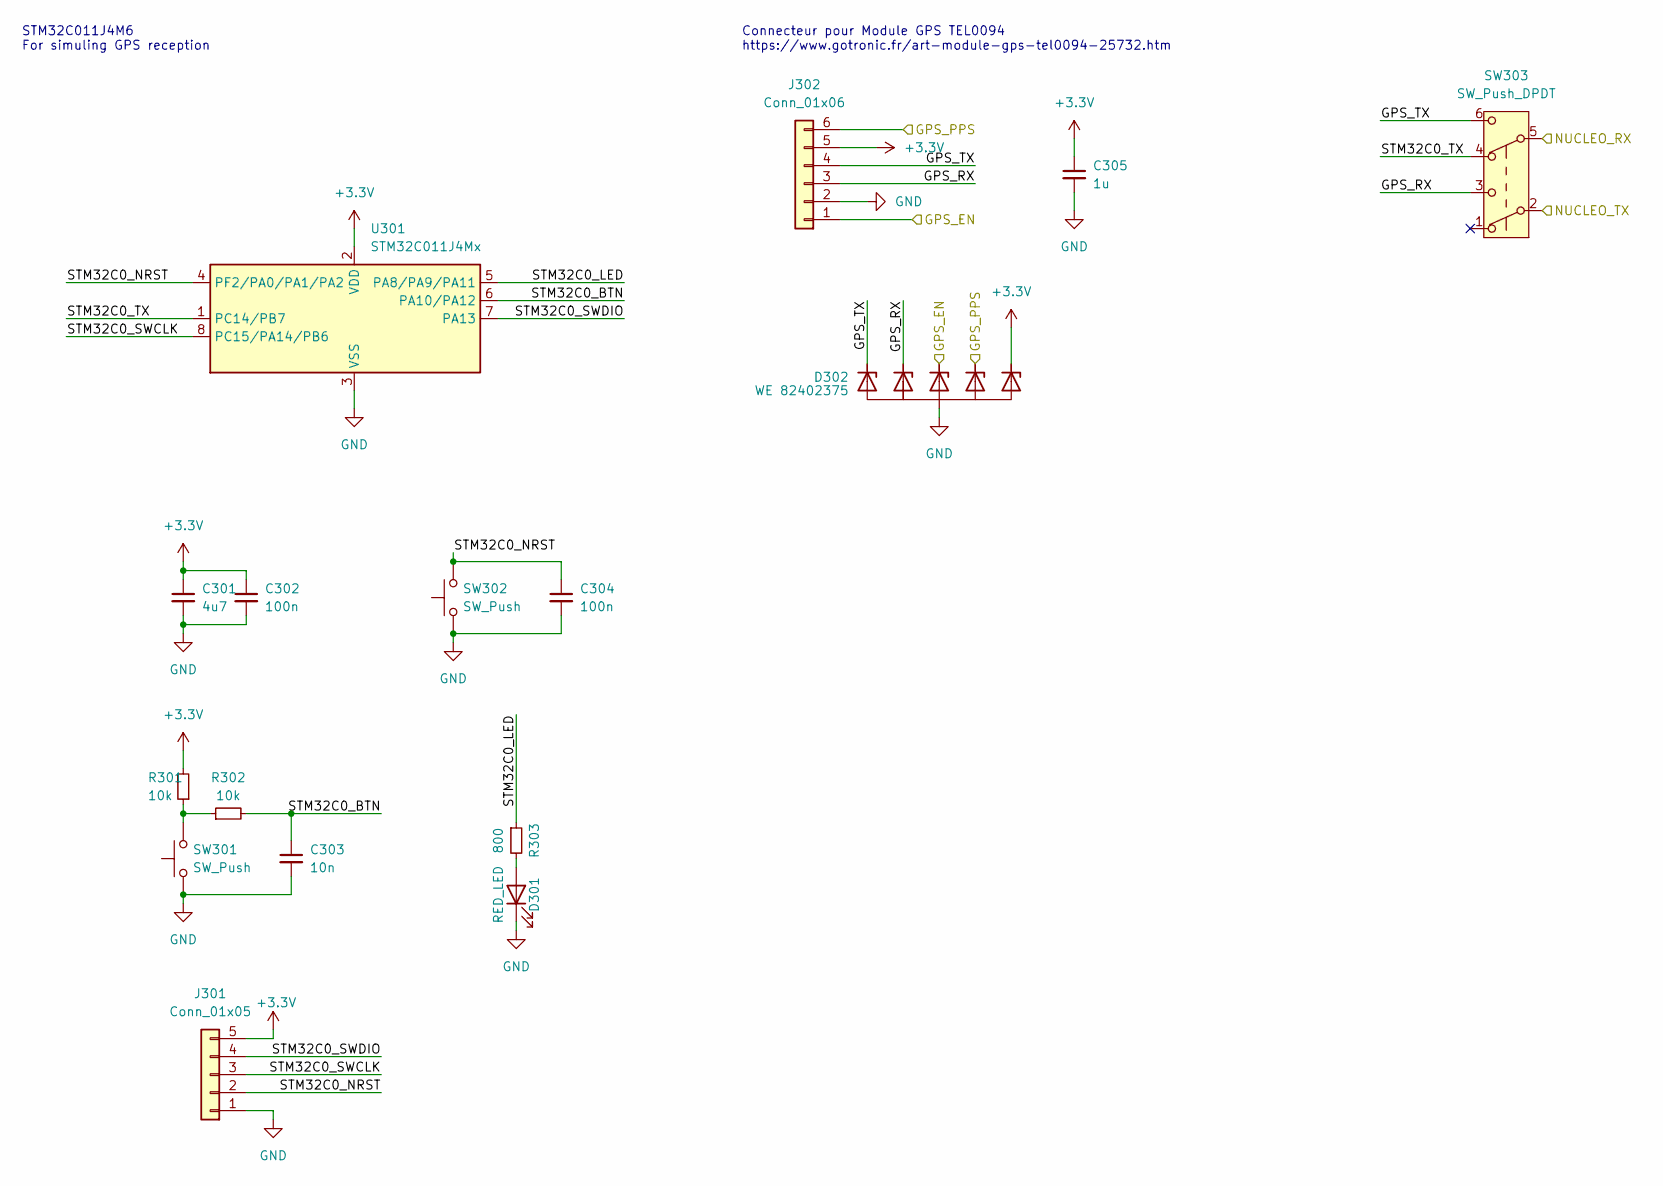
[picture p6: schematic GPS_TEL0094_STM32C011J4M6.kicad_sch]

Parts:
C301: 4u7; C_0402_1005Metric; MPN WE 885012105008
C302, C304: 100n; C_0402_1005Metric; MPN WE 885012105018
C303: 10n; C_0402_1005Metric; MPN WE 885012205050
C305: 1u; C_0402_1005Metric; MPN WE 885012105012
D301: RED_LED; LED_0603_1608Metric; MPN WE 150060RS55040
D302: WE 82402375; SC70-6L; MPN WE 82402375
J301: Conn_01x05; PinHeader_1x05_P2.54mm_Horizontal
J302: Conn_01x06; JST_XH_S6B-XH-A_1x06_P2.50mm_Horizontal; MPN S6B-XH-A(lf)(sn)
R301, R302: 10k; R_0402_1005Metric
R303: 800; R_0402_1005Metric
SW301, SW302: SW_Push; SW_Push_1P1T_NO_6x6mm_H9.5mm; MPN WE 430182070816
SW303: SW_Push_DPDT; SW_DPDT_CK_JS202011JCQN; MPN JS202011JCQN
U301: STM32C011J4Mx; SOIC-8_3.9x4.9mm_P1.27mm; MPN STM32C011J4M6

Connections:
+3.3V: C301.1, C302.1, C305.1, D302.1 (I/O), J301.5, J302.5, R301.2, U301.2 (VDD); also elsewhere on the board
/GPS_TEL0094_STM32C011J4M6/GPS_EN: D302.4 (I/O), J302.1; also elsewhere on the board
/GPS_TEL0094_STM32C011J4M6/GPS_PPS: D302.3 (I/O), J302.6; also elsewhere on the board
/GPS_TEL0094_STM32C011J4M6/GPS_RX: D302.5 (I/O), J302.3, SW303.3 (C)
/GPS_TEL0094_STM32C011J4M6/GPS_TX: D302.6 (I/O), J302.4, SW303.6 (C)
/GPS_TEL0094_STM32C011J4M6/NUCLEO_RX: SW303.5 (B); also elsewhere on the board
/GPS_TEL0094_STM32C011J4M6/NUCLEO_TX: SW303.2 (B); also elsewhere on the board
/GPS_TEL0094_STM32C011J4M6/STM32C0_BTN: C303.1, R302.2, U301.6 (PA10/PA12)
/GPS_TEL0094_STM32C011J4M6/STM32C0_LED: R303.1, U301.5 (PA8/PA9/PA11)
/GPS_TEL0094_STM32C011J4M6/STM32C0_NRST: C304.1, J301.2, SW302.2, U301.4 (PF2/PA0/PA1/PA2)
/GPS_TEL0094_STM32C011J4M6/STM32C0_SWCLK: J301.3, U301.8 (PC15/PA14/PB6)
/GPS_TEL0094_STM32C011J4M6/STM32C0_SWDIO: J301.4, U301.7 (PA13)
/GPS_TEL0094_STM32C011J4M6/STM32C0_TX: SW303.4 (A), U301.1 (PC14/PB7)
GND: C301.2, C302.2, C303.2, C304.2, C305.2, D301.1 (K), D302.2 (GND), J301.1, J302.2, SW301.1, SW302.1, U301.3 (VSS); also elsewhere on the board
unnamed: D301.2 (A), R303.2
unnamed: R301.1, R302.1, SW301.2

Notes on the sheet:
Connecteur pour Module GPS TEL0094 https://www.gotronic.fr/art-module-gps-tel0094-25732.htm
STM32C011J4M6 For simuling GPS reception

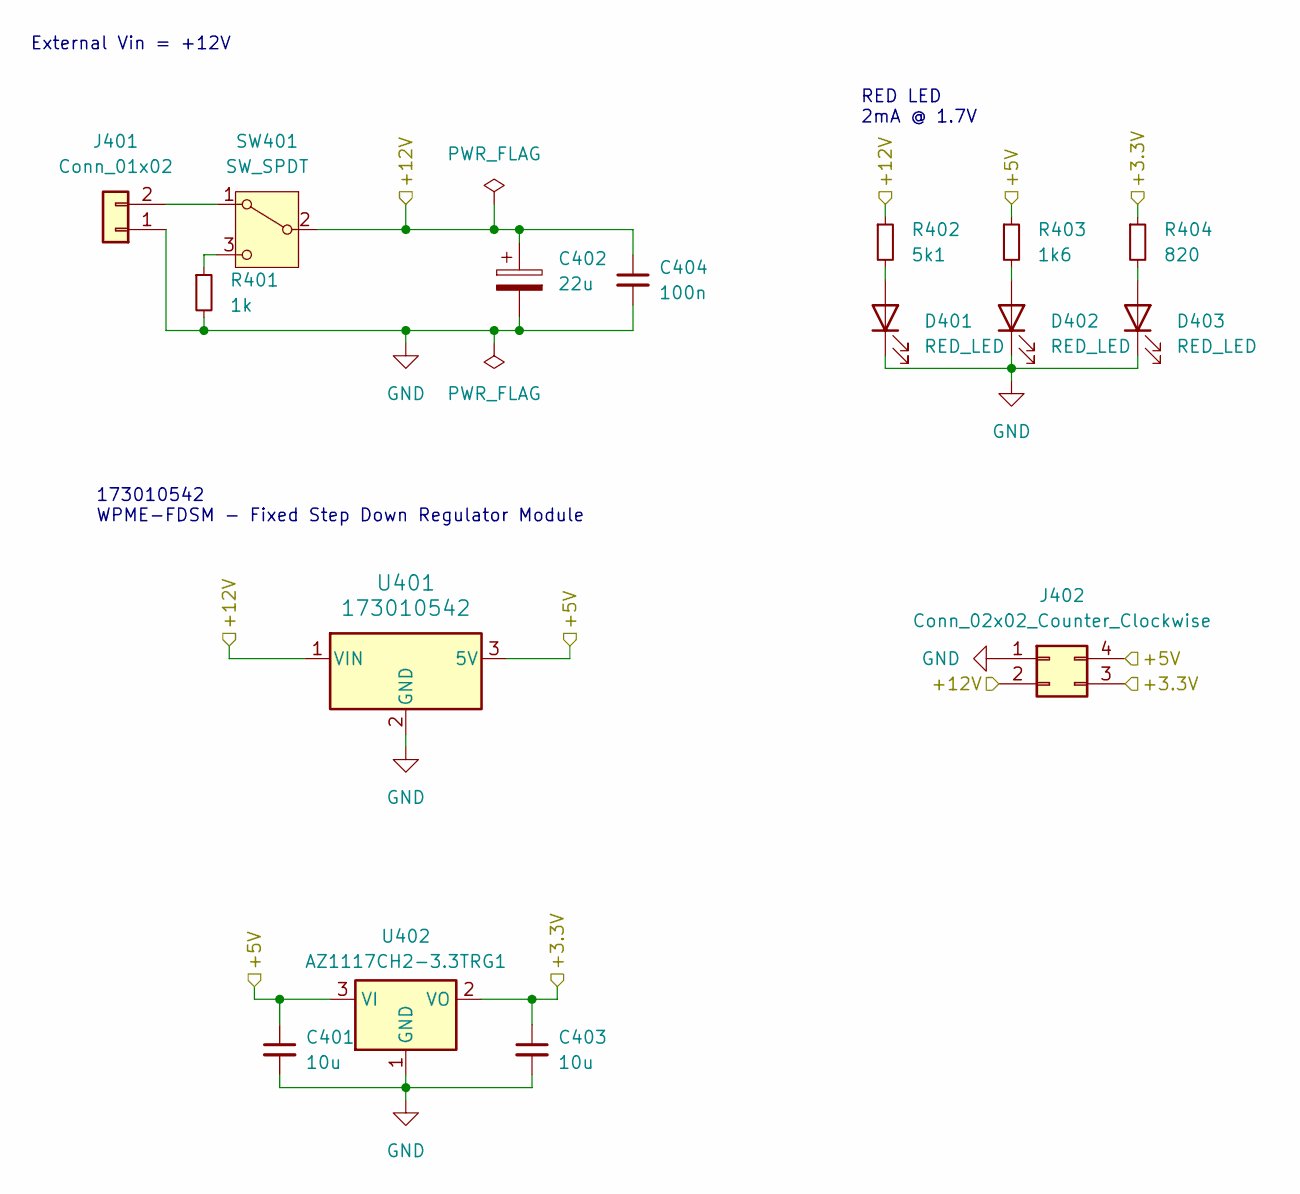
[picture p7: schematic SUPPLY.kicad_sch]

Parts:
C401, C403: 10u; C_0402_1005Metric; MPN WE 885012105020
C402: 22u; CP_Elec_5x5.4; MPN WE 865060442002
C404: 100n; C_0402_1005Metric; MPN WE 885012105018
D401, D402, D403: RED_LED; LED_0603_1608Metric; MPN WE 150060RS55040
J401: Conn_01x02; JST_XH_S2B-XH-A_1x02_P2.50mm_Horizontal; MPN S2B-XH-A(lf)(sn)
J402: Conn_02x02_Counter_Clockwise; PinHeader_2x02_P2.54mm_Vertical_SMD; MPN WE 61000421121
R401: 1k; R_0805_2012Metric
R402: 5k1; R_0402_1005Metric
R403: 1k6; R_0402_1005Metric
R404: 820; R_0402_1005Metric
SW401: SW_SPDT; 472121020311; MPN WE 472121020311
U401: 173010542; 173010xxx; MPN WE 173010542
U402: AZ1117CH2-3.3TRG1; SOT-223-3_TabPin2; MPN AZ1117CH2-3.3TRG1

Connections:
+3.3V: C403.1, J402.3, R404.1, U402.2 (VO); also elsewhere on the board
+5V: C401.1, J402.4, R403.1, U401.3 (5V), U402.3 (VI); also elsewhere on the board
+12V: C402.1, C404.1, J402.2, R402.1, SW401.2 (B), U401.1 (VIN); also elsewhere on the board
GND: C401.2, C402.2, C403.2, C404.2, D401.1 (K), D402.1 (K), D403.1 (K), J401.1, J402.1, R401.2, U401.2 (GND), U402.1 (GND); also elsewhere on the board
unnamed: D401.2 (A), R402.2
unnamed: D402.2 (A), R403.2
unnamed: D403.2 (A), R404.2
unnamed: J401.2, SW401.1 (A)
unnamed: R401.1, SW401.3 (C)

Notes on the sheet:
RED LED 2mA @ 1.7V
173010542 WPME-FDSM - Fixed Step Down Regulator Module
External Vin = +12V

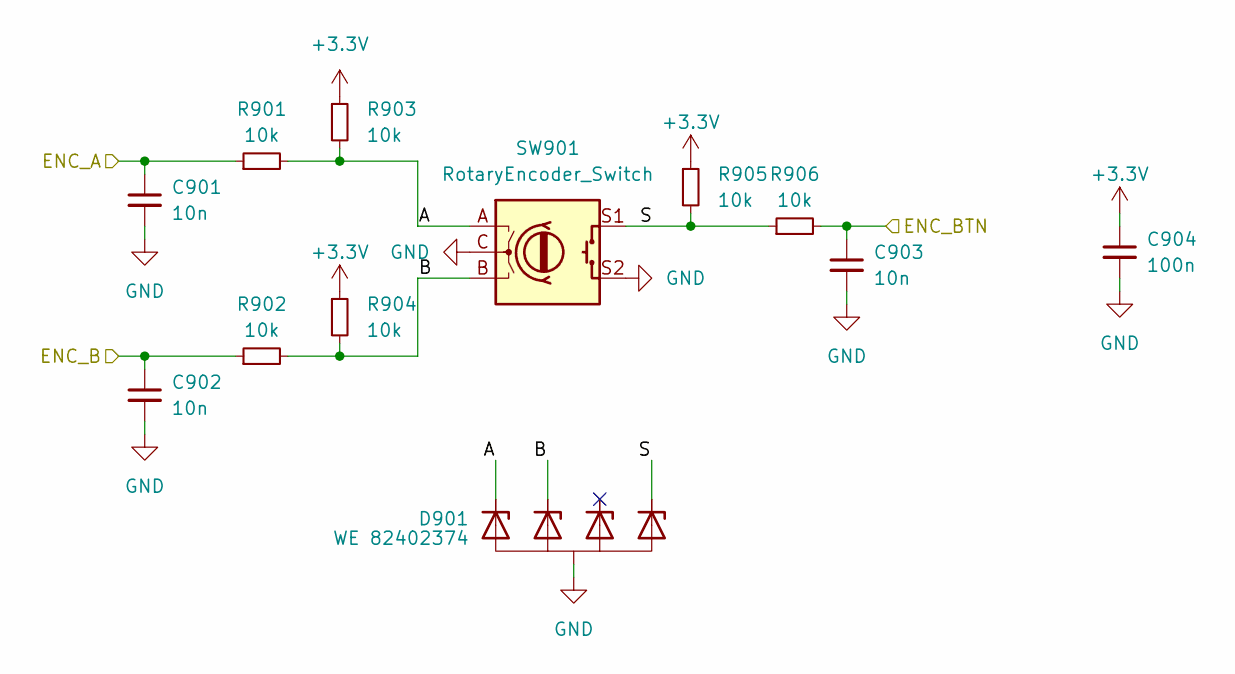
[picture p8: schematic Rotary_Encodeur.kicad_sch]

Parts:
C901, C902, C903: 10n; C_0402_1005Metric; MPN WE 885012205050
C904: 100n; C_0402_1005Metric; MPN WE 885012105018
D901: WE 82402374; SC70-5L; MPN WE 82402374
R901, R902, R903, R904, R905, R906: 10k; R_0402_1005Metric
SW901: RotaryEncoder_Switch; 482016514001_Mechanical_Incremental_Encoder_Switch; MPN WE 482016514001

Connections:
+3.3V: C904.1, R903.1, R904.1, R905.1; also elsewhere on the board
/NUCLEO_L476RG/ENC_BTN: C903.1, R906.2; also elsewhere on the board
/NUCLEO_L476RG/TIM2_CH1_ENC_A: C901.1, R901.1; also elsewhere on the board
/NUCLEO_L476RG/TIM2_CH2_ENC_B: C902.1, R902.1; also elsewhere on the board
/Rotary_Encodeur/A: D901.5 (I/O), R901.2, R903.2, SW901.A
/Rotary_Encodeur/B: D901.4 (I/O), R902.2, R904.2, SW901.B
/Rotary_Encodeur/S: D901.1 (I/O), R905.2, R906.1, SW901.S1
GND: C901.2, C902.2, C903.2, C904.2, D901.2 (GND), SW901.C, SW901.S2; also elsewhere on the board

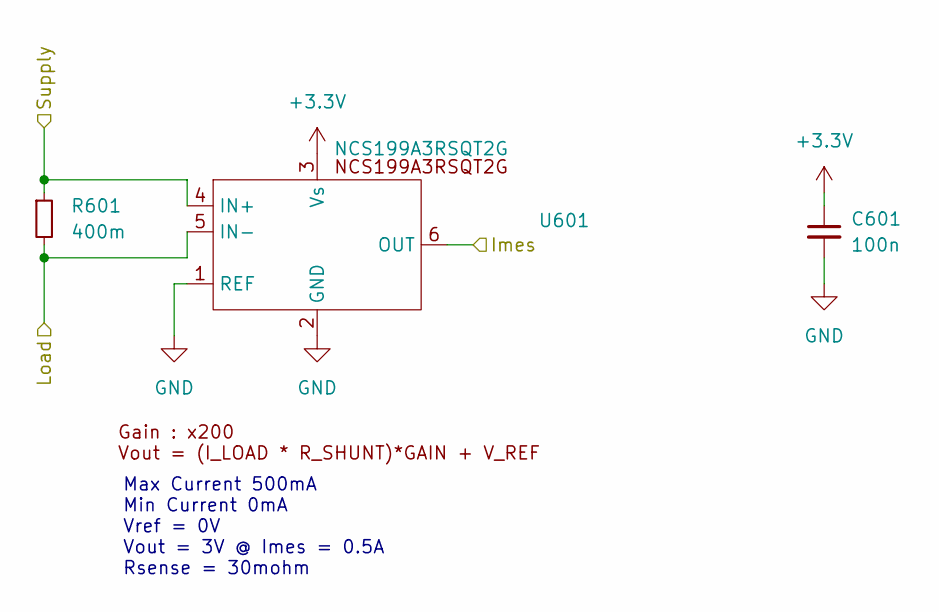
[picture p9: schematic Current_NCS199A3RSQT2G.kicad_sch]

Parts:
C601: 100n; C_0402_1005Metric; MPN WE 885012105018
R601: 400m; R_0402_1005Metric; MPN WW04PR400FTL
U601: NCS199A3RSQT2G; SOT-363_SC-70-6; MPN NCS199A3RSQT2G

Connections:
+3.3V: C601.1, U601.3 (Vs); also elsewhere on the board
+5V: R601.1, U601.4 (IN+); also elsewhere on the board
/Current_NCS199A3RSQT2G/Imes: U601.6 (OUT); also elsewhere on the board
/Current_NCS199A3RSQT2G/Load: R601.2, U601.5 (IN-); also elsewhere on the board
GND: C601.2, U601.1 (REF), U601.2 (GND); also elsewhere on the board

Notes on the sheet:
Max Current 500mA Min Current 0mA Vref = 0V Vout = 3V @ Imes = 0.5A Rsense = 30mohm

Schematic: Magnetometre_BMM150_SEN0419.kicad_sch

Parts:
C701: 1u; C_0402_1005Metric; MPN WE 885012105012
D701, D702: WE 82402374; SC70-5L; MPN WE 82402374
J701: Conn_01x09; JST_XH_S9B-XH-A_1x09_P2.50mm_Horizontal; MPN S9B-XH-A (LF)(SN)

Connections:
+3.3V: C701.1, D701.3 (I/O), J701.1; also elsewhere on the board
/Magnetometre_BMM150_SEN0419/INT: D702.5 (I/O), J701.9; also elsewhere on the board
/Magnetometre_BMM150_SEN0419/SPI_CLK: D701.4 (I/O), J701.3; also elsewhere on the board
/Magnetometre_BMM150_SEN0419/SPI_CS: D702.3 (I/O), J701.6; also elsewhere on the board
/Magnetometre_BMM150_SEN0419/SPI_MISO: D702.1 (I/O), J701.5; also elsewhere on the board
/Magnetometre_BMM150_SEN0419/SPI_MOSI: D701.5 (I/O), J701.4; also elsewhere on the board
/Magnetometre_BMM150_SEN0419/STATUS: D702.4 (I/O), J701.8; also elsewhere on the board
GND: C701.2, D701.2 (GND), D702.2 (GND), J701.2, J701.7; also elsewhere on the board

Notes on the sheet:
Magnétomètre 3 axes BMM150 SEN0419

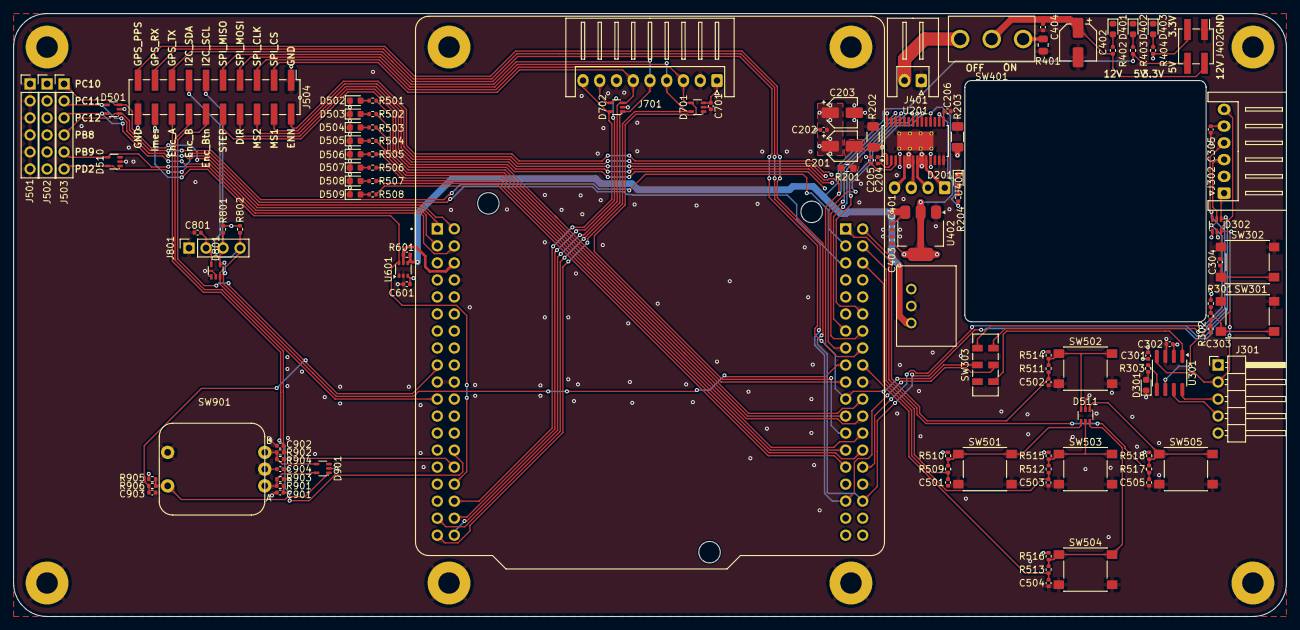
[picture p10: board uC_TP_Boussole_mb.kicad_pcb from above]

Board: 4 copper layers, 190.0 x 90.0 mm, 121 parts (1 on the bottom side), 89 nets.

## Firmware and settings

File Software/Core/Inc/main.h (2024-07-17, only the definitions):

#define B1_Pin GPIO_PIN_13
#define B1_GPIO_Port GPIOC
#define SPI_CS_Pin GPIO_PIN_0
#define SPI_CS_GPIO_Port GPIOC
#define MAGNETO_STATUS_Pin GPIO_PIN_1
#define MAGNETO_STATUS_GPIO_Port GPIOC
#define USART_TX_Pin GPIO_PIN_2
#define USART_TX_GPIO_Port GPIOA
#define USART_RX_Pin GPIO_PIN_3
#define USART_RX_GPIO_Port GPIOA
#define LD2_Pin GPIO_PIN_5
#define LD2_GPIO_Port GPIOA
#define STEPPER_DIR_Pin GPIO_PIN_7
#define STEPPER_DIR_GPIO_Port GPIOA
#define GPS_PPS_Pin GPIO_PIN_4
#define GPS_PPS_GPIO_Port GPIOC
#define BTN_TOP_Pin GPIO_PIN_5
#define BTN_TOP_GPIO_Port GPIOC
#define MAGNETO_INT_Pin GPIO_PIN_0
#define MAGNETO_INT_GPIO_Port GPIOB
#define LED_3_Pin GPIO_PIN_1
#define LED_3_GPIO_Port GPIOB
#define LED_1_Pin GPIO_PIN_2
#define LED_1_GPIO_Port GPIOB
#define BTN_TOPB11_Pin GPIO_PIN_11
#define BTN_TOPB11_GPIO_Port GPIOB
#define GPS_ENN_Pin GPIO_PIN_13
#define GPS_ENN_GPIO_Port GPIOB
#define LED_6_Pin GPIO_PIN_14
#define LED_6_GPIO_Port GPIOB
#define LED_4_Pin GPIO_PIN_15
#define LED_4_GPIO_Port GPIOB
#define BTN_CENTER_Pin GPIO_PIN_6
#define BTN_CENTER_GPIO_Port GPIOC
#define LED_0_Pin GPIO_PIN_7
#define LED_0_GPIO_Port GPIOC
#define BTN_RIGHT_Pin GPIO_PIN_8
#define BTN_RIGHT_GPIO_Port GPIOC
#define BTN_LEFT_Pin GPIO_PIN_9
#define BTN_LEFT_GPIO_Port GPIOC
#define LED_2_Pin GPIO_PIN_8
#define LED_2_GPIO_Port GPIOA
#define STEPPER_MS1_Pin GPIO_PIN_11
#define STEPPER_MS1_GPIO_Port GPIOA
#define STEPPER_ENN_Pin GPIO_PIN_12
#define STEPPER_ENN_GPIO_Port GPIOA
#define TMS_Pin GPIO_PIN_13
#define TMS_GPIO_Port GPIOA
#define TCK_Pin GPIO_PIN_14
#define TCK_GPIO_Port GPIOA
#define ENC_BTN_Pin GPIO_PIN_15
#define ENC_BTN_GPIO_Port GPIOA
#define PC10_Pin GPIO_PIN_10
#define PC10_GPIO_Port GPIOC
#define LED_5_Pin GPIO_PIN_4
#define LED_5_GPIO_Port GPIOB
#define LED_7_Pin GPIO_PIN_5
#define LED_7_GPIO_Port GPIOB

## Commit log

2024-03-03 update schematic
    [Current_NCS199A3RSQT2G.kicad_sch, GPS_TEL0094_STM32C011J4M6.kicad_sch, MAGNETOMETER_MMC5603.kicad_sch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]
2024-03-04 starting pin out nucleo
    [Current_NCS199A3RSQT2G.kicad_sch, GPS_TEL0094_STM32C011J4M6.kicad_sch, Magnetometre_BMM150_SEN0419.kicad_sch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]
2024-03-05 update pcb
    [TMC2225_Driver.kicad_sch, uC_TP_Boussole_mb.kicad_sch]
2024-03-06 update ppcb
    [Current_NCS199A3RSQT2G.kicad_sch, NUCLEO_L476RG.kicad_sch, uC_TP_Boussole_mb.kicad_pcb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]
2024-03-20 finalize pcb
    [GPS_TEL0094_STM32C011J4M6.kicad_sch, Magnetometre_BMM150_SEN0419.kicad_sch, NUCLEO_L476RG.kicad_sch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]
2024-03-21 change SBC01 footprint, add via GND, clean error and export gerbers
    [OLED_SSD1306.kicad_sch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]
2024-03-24 create BOM, update MPN
    [GPS_TEL0094_STM32C011J4M6.kicad_sch, NUCLEO_L476RG.kicad_sch, SUPPLY.kicad_sch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]
2024-07-17 create rev 2 pcb
    [20240327_BOM.ods, Current_NCS199A3RSQT2G.kicad_sch, GPS_TEL0094_STM32C011J4M6.kicad_sch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]
2024-09-06 export files for production
    [bom_by_value_footprint.csv, bom_by_value_footprint.ods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]

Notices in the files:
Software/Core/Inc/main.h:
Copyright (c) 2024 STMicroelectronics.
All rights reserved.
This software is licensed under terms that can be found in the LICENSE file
